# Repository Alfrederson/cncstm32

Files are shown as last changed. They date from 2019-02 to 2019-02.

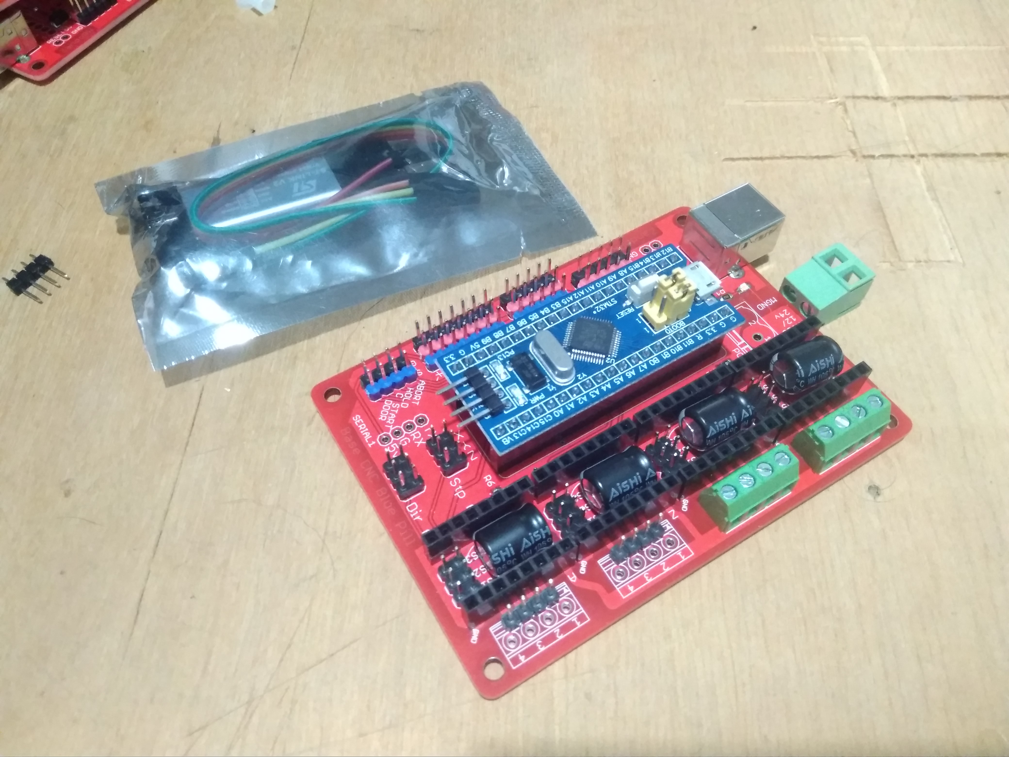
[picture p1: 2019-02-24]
physical board.jpg

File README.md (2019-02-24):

# cncstm32
CNC Base for Blue Pill

To be used with this port of GRBL for STM32F103F8T6: https://github.com/usbcnc/grbl or with Yaroslav's bugfixed and improved version:
https://github.com/yaroslavVl/6-AXIS-USBCNC-GRBL .

This board works with either 3d printer drivers or with external drivers using MKS-CD adapter.
An adapter could be made so that drivers that use a common 5V instead of a common GND for step/dir/enable (e.g: the aliexpress TB6600 drivers that come in a black aluminum enclosure) could be used as well.

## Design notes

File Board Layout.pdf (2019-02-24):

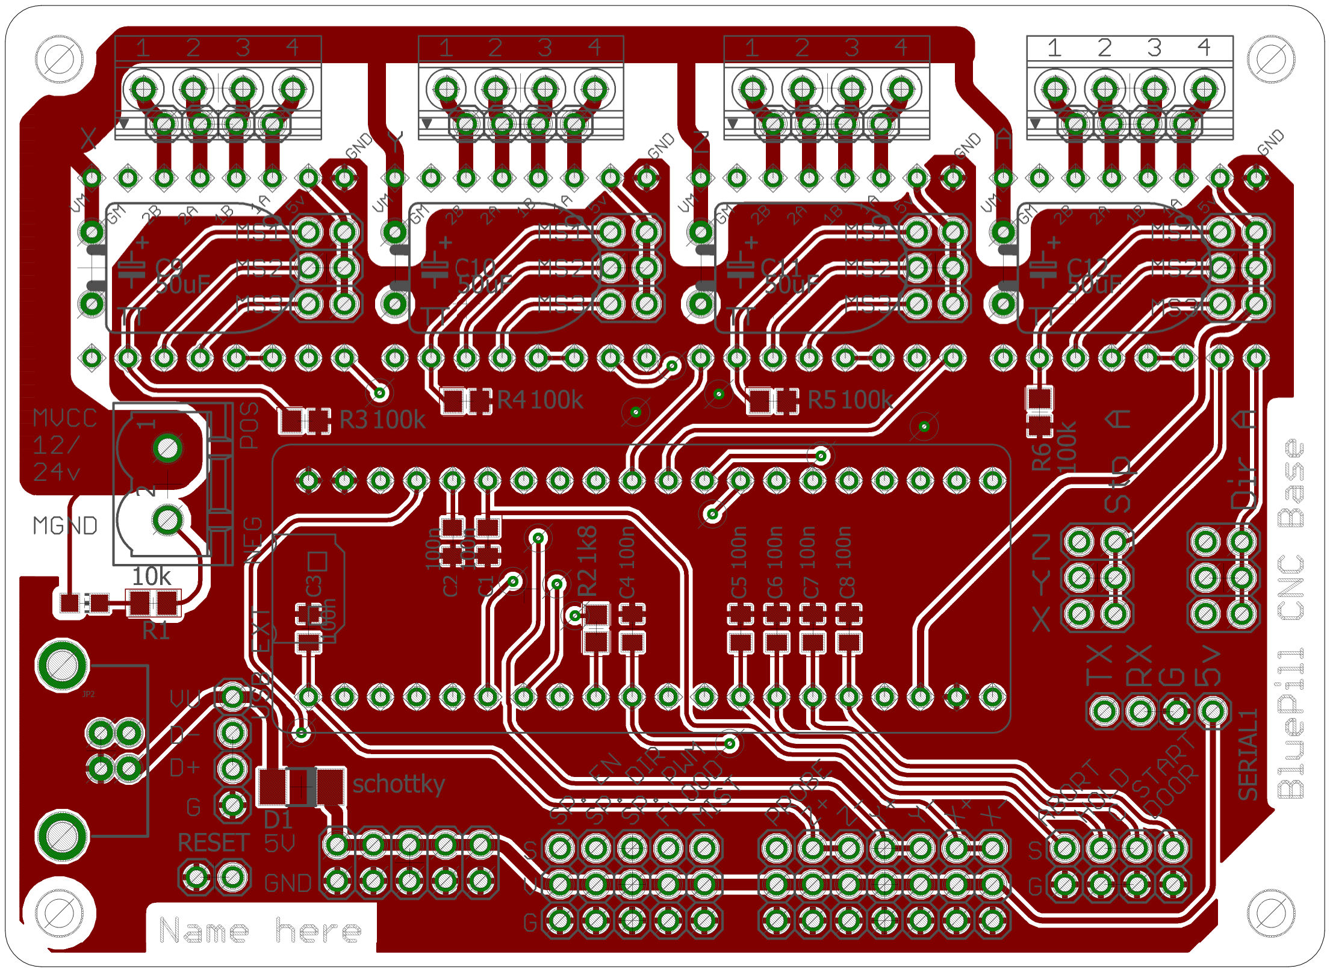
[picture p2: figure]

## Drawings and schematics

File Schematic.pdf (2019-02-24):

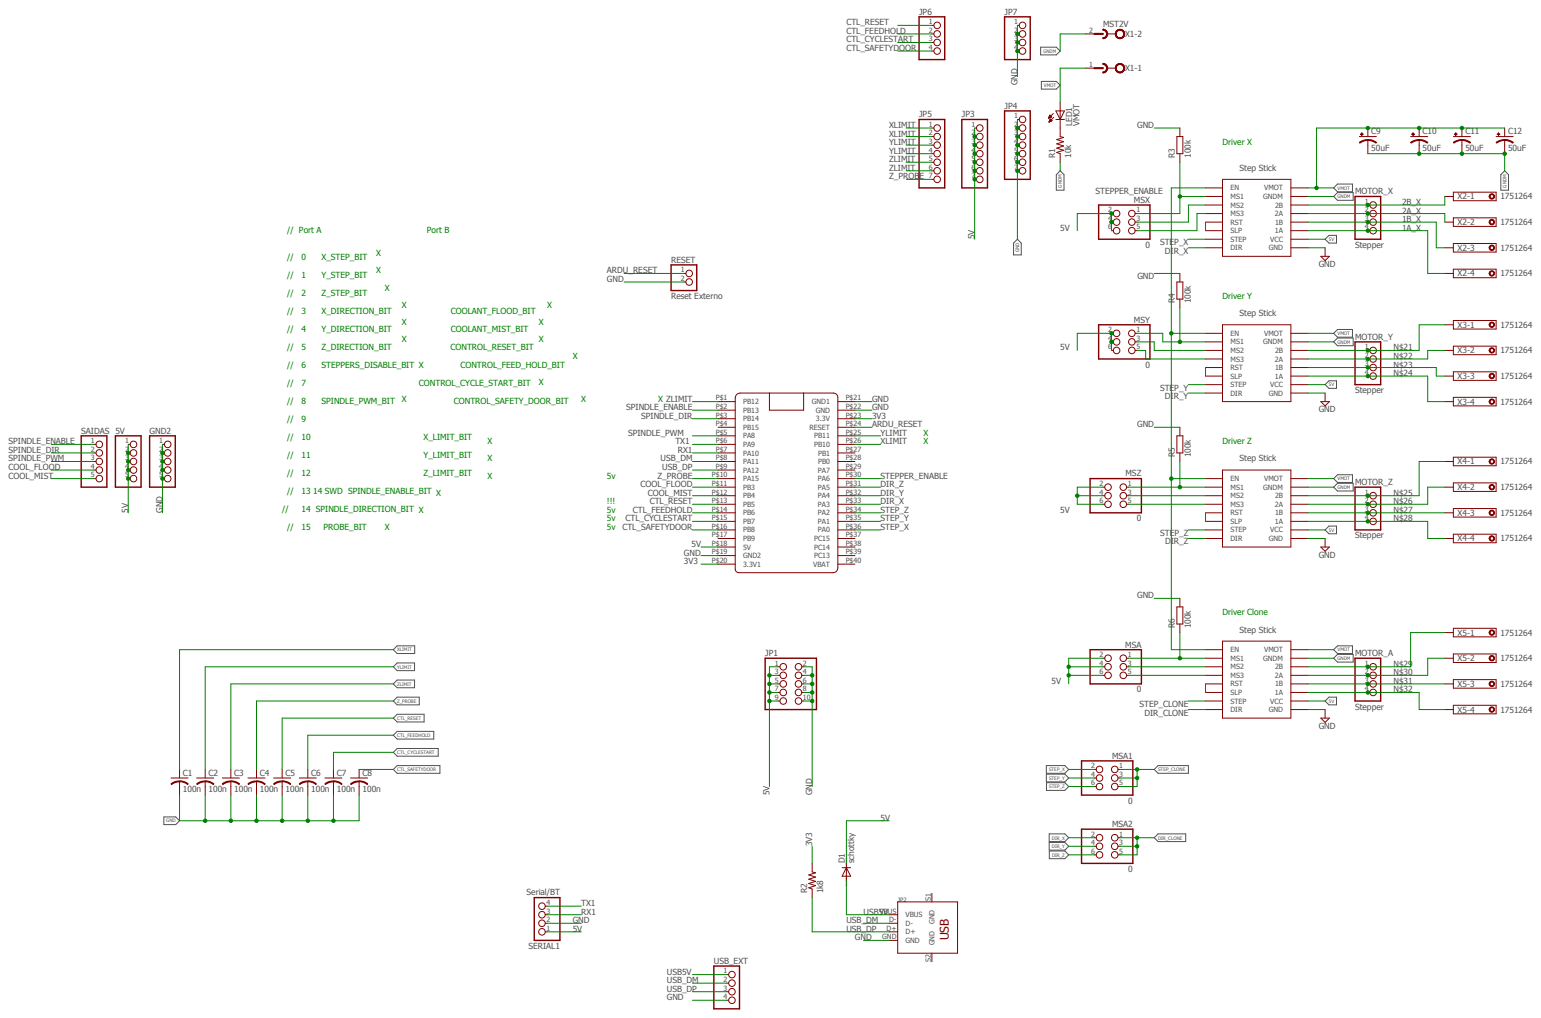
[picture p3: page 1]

3 | 1B_X
4 | 1A_X

2 | N$22
4 | N$24

2 | N$26

2 | N$30

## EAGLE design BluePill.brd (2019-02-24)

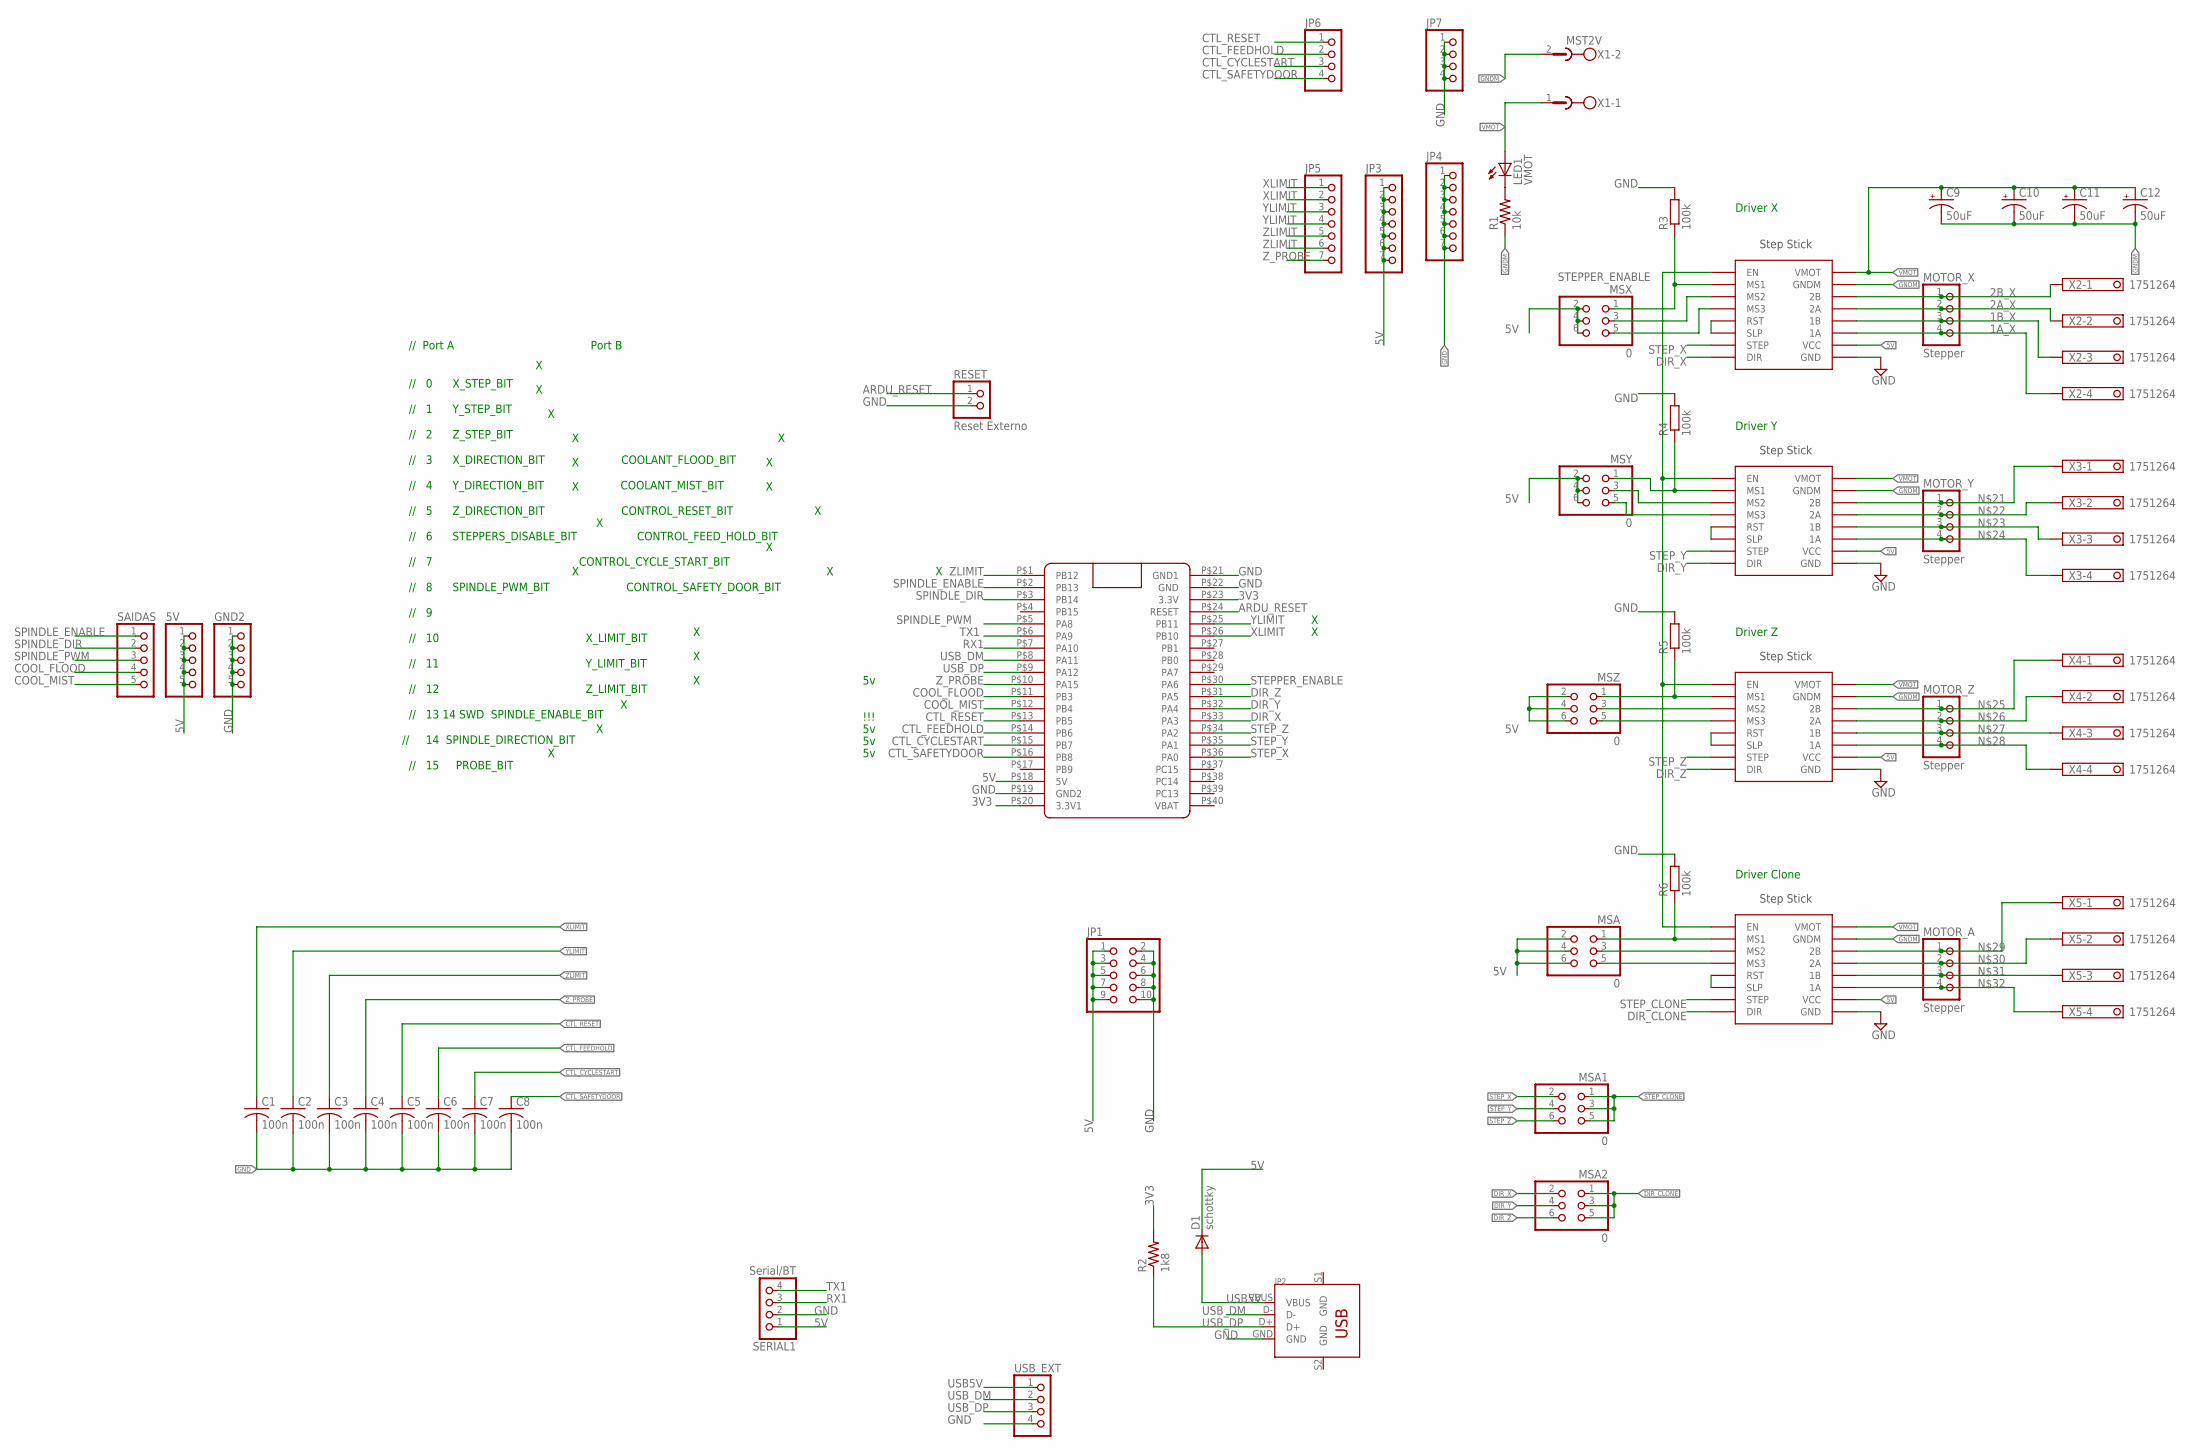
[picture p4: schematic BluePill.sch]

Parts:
5V: PINHD-1X5; 1X05
C1, C2, C3, C4, C5, C6, C7, C8: 100n; C0805K
C9, C10, C11, C12: 50uF; TT5D9L
D1: schottky; DO-214AC
DRIVER_CLONE: STEP-STICK
DRIVER_X: STEP-STICK
DRIVER_Y: STEP-STICK
DRIVER_Z: STEP-STICK
GND2: PINHD-1X5; 1X05
JP1: PINHD-2X5; 2X05
JP2: DIP-USB-B-TYPE-FMAL(4+2P-2.0-90D); USB4+2-2.5-90D-15.8X12MM
JP3, JP4, JP5: PINHD-1X7; 1X07
JP6, JP7: PINHD-1X4; 1X04
LED1: VMOT; CHIP-LED0805
MOTOR_A: Stepper; 1X04
MOTOR_X: Stepper; 1X04
MOTOR_Y: Stepper; 1X04
MOTOR_Z: Stepper; 1X04
MSA, MSA1, MSA2: 0; 2X03
MSX: 0; 2X03
MSY: 0; 2X03
MSZ: 0; 2X03
R1: 10k; M0805
R2: 1k8; R0805
R3, R4, R5, R6: 100k; R0805
RESET: Reset Externo; 1X02
SAIDAS: PINHD-1X5; 1X05
SERIAL1: Serial/BT; 1X04
U$1: BLUE_PILL
USB_EXT: PINHD-1X4; 1X04
X1: MST2V; MSTBV2
X2, X3, X4, X5: 1751264

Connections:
1A_X: DRIVER_X.1A, MOTOR_X.4, X2.4
1B_X: DRIVER_X.1B, MOTOR_X.3, X2.3
2A_X: DRIVER_X.2A, MOTOR_X.2, X2.2
2B_X: DRIVER_X.2B, MOTOR_X.1, X2.1
3V3: R2.2, U$1.P$20 (3.3V1), U$1.P$23 (3.3V)
5V: 5V.1, 5V.2, 5V.3, 5V.4, 5V.5, D1.C, DRIVER_CLONE.VCC, DRIVER_X.VCC, DRIVER_Y.VCC, DRIVER_Z.VCC, JP1.1, JP1.3, JP1.5, JP1.7, JP1.9, JP3.1, JP3.2, JP3.3, JP3.4, JP3.5, JP3.6, JP3.7, MSA.2, MSA.4, MSA.6, MSX.2, MSX.4, MSX.6, MSY.2, MSY.4, MSY.6, MSZ.2, MSZ.4, MSZ.6, SERIAL1.1, U$1.P$18 (5V)
AMS1: DRIVER_CLONE.MS1, MSA.1, R6.1
AMS2: DRIVER_CLONE.MS2, MSA.3
AMS3: DRIVER_CLONE.MS3, MSA.5
ARDU_RESET: RESET.1, U$1.P$24 (RESET)
COOL_FLOOD: SAIDAS.4, U$1.P$11 (PB3)
COOL_MIST: SAIDAS.5, U$1.P$12 (PB4)
CTL_CYCLESTART: C7.1, JP6.3, U$1.P$15 (PB7)
CTL_FEEDHOLD: C6.1, JP6.2, U$1.P$14 (PB6)
CTL_RESET: C5.1, JP6.1, U$1.P$13 (PB5)
CTL_SAFETYDOOR: C8.1, JP6.4, U$1.P$16 (PB8)
DIR_CLONE: DRIVER_CLONE.DIR, MSA2.1, MSA2.3, MSA2.5
DIR_X: DRIVER_X.DIR, MSA2.2, U$1.P$33 (PA3)
DIR_Y: DRIVER_Y.DIR, MSA2.4, U$1.P$32 (PA4)
DIR_Z: DRIVER_Z.DIR, MSA2.6, U$1.P$31 (PA5)
GND: C1.2, C2.2, C3.2, C4.2, C5.2, C6.2, C7.2, C8.2, DRIVER_CLONE.GND, DRIVER_X.GND, DRIVER_Y.GND, DRIVER_Z.GND, GND2.1, GND2.2, GND2.3, GND2.4, GND2.5, JP1.2, JP1.4, JP1.6, JP1.8, JP1.10, JP2.GND, JP4.1, JP4.2, JP4.3, JP4.4, JP4.5, JP4.6, JP4.7, JP7.1, JP7.2, JP7.3, JP7.4, R3.2, R4.2, R5.2, R6.2, RESET.2, SERIAL1.2, U$1.P$19 (GND2), U$1.P$21 (GND1), U$1.P$22 (GND), USB_EXT.4
GNDM: C9.-, C10.-, C11.-, C12.-, DRIVER_CLONE.GNDM, DRIVER_X.GNDM, DRIVER_Y.GNDM, DRIVER_Z.GNDM, R1.1, X1.2
MS1: DRIVER_X.MS1, MSX.1, R3.1
MS2: DRIVER_X.MS2, MSX.3
MS3: DRIVER_X.MS3, MSX.5
unnamed: DRIVER_X.RST, DRIVER_X.SLP
unnamed: DRIVER_Y.RST, DRIVER_Y.SLP
unnamed: DRIVER_Z.RST, DRIVER_Z.SLP
unnamed: DRIVER_CLONE.RST, DRIVER_CLONE.SLP
unnamed: DRIVER_Y.2B, MOTOR_Y.1, X3.1
unnamed: DRIVER_Y.2A, MOTOR_Y.2, X3.2
unnamed: DRIVER_Y.1B, MOTOR_Y.3, X3.3
unnamed: DRIVER_Y.1A, MOTOR_Y.4, X3.4
unnamed: DRIVER_Z.2B, MOTOR_Z.1, X4.1
unnamed: DRIVER_Z.2A, MOTOR_Z.2, X4.2
unnamed: DRIVER_Z.1B, MOTOR_Z.3, X4.3
unnamed: DRIVER_Z.1A, MOTOR_Z.4, X4.4
unnamed: DRIVER_CLONE.2B, MOTOR_A.1, X5.1
unnamed: DRIVER_CLONE.2A, MOTOR_A.2, X5.2
unnamed: DRIVER_CLONE.1B, MOTOR_A.3, X5.3
unnamed: DRIVER_CLONE.1A, MOTOR_A.4, X5.4
unnamed: LED1.C, R1.2
RX1: SERIAL1.3, U$1.P$7 (PA10)
SPINDLE_DIR: SAIDAS.2, U$1.P$3 (PB14)
SPINDLE_ENABLE: SAIDAS.1, U$1.P$2 (PB13)
SPINDLE_PWM: SAIDAS.3, U$1.P$5 (PA8)
STEPPER_ENABLE: DRIVER_CLONE.EN, DRIVER_X.EN, DRIVER_Y.EN, DRIVER_Z.EN, U$1.P$30 (PA6)
STEP_CLONE: DRIVER_CLONE.SPT (STEP), MSA1.1, MSA1.3, MSA1.5
STEP_X: DRIVER_X.SPT (STEP), MSA1.2, U$1.P$36 (PA0)
STEP_Y: DRIVER_Y.SPT (STEP), MSA1.4, U$1.P$35 (PA1)
STEP_Z: DRIVER_Z.SPT (STEP), MSA1.6, U$1.P$34 (PA2)
TX1: SERIAL1.4, U$1.P$6 (PA9)
USB5V: D1.A, JP2.VBUS, USB_EXT.1
USB_DM: JP2.D-, U$1.P$8 (PA11), USB_EXT.2
USB_DP: JP2.D+, R2.1, U$1.P$9 (PA12), USB_EXT.3
VMOT: C9.+, C10.+, C11.+, C12.+, DRIVER_CLONE.VMOT, DRIVER_X.VMOT, DRIVER_Y.VMOT, DRIVER_Z.VMOT, LED1.A, X1.1
XLIMIT: C1.1, JP5.1, JP5.2, U$1.P$26 (PB10)
YLIMIT: C2.1, JP5.3, JP5.4, U$1.P$25 (PB11)
YMS1: DRIVER_Y.MS1, MSY.1, R4.1
YMS2: DRIVER_Y.MS2, MSY.3
YMS3: DRIVER_Y.MS3, MSY.5
ZLIMIT: C3.1, JP5.5, JP5.6, U$1.P$1 (PB12)
ZMS1: DRIVER_Z.MS1, MSZ.1, R5.1
ZMS2: DRIVER_Z.MS2, MSZ.3
ZMS3: DRIVER_Z.MS3, MSZ.5
Z_PROBE: C4.1, JP5.7, U$1.P$10 (PA15)

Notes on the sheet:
Driver X
Driver Y
Driver Z
Driver Clone
// Port A Port B // 0 X_STEP_BIT // 1 Y_STEP_BIT // 2 Z_STEP_BIT // 3 X_DIRECTION_BIT COOLANT_FLOOD_BIT // 4 Y_DIRECTION_BIT COOLANT_MIST_BIT // 5 Z_DIRECTION_BIT CONTROL_RESET_BIT // 6 STEPPERS_DISABLE_BIT CONTROL_FEED_HOLD_BIT // 7 CONTROL_CYCLE_START_BIT // 8 SPINDLE_PWM_BIT CONTROL_SAFETY_DOOR_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
!!!

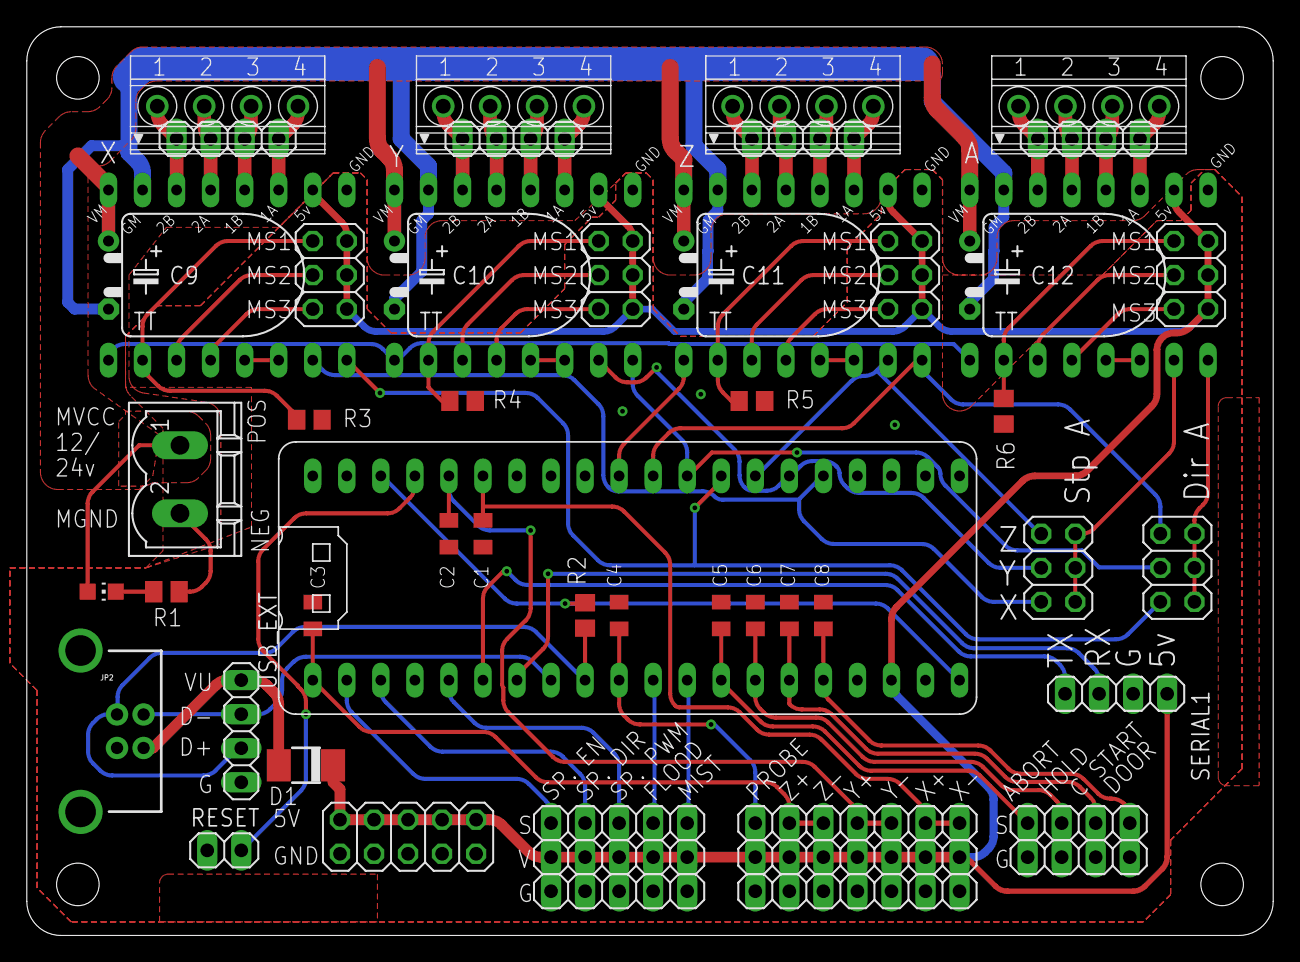
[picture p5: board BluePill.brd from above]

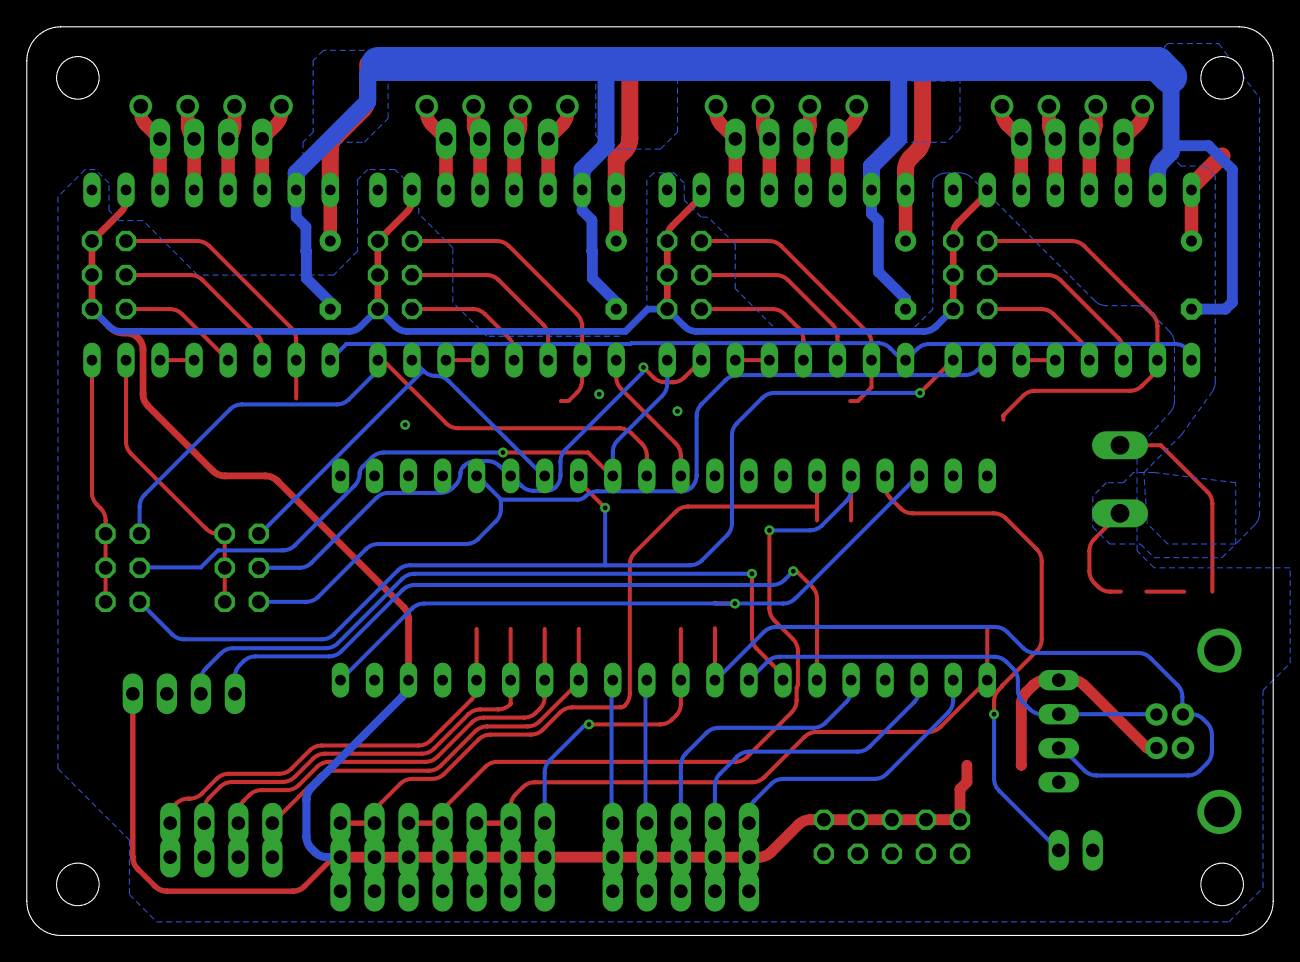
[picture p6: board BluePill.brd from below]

Board: 2 copper layers, 93.0 x 67.8 mm, 53 parts (4 on the bottom side), 66 nets.

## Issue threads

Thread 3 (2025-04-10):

pcb problem ?

sasan18s, 2025-04-10:
hi . thank for this good design and share it with others . your a good man ,
i have some problem in pcb file :

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

and some question ....
-can we use some EEPROM  ic to make this circuit faster and responsive for longer time like some AT24C128  ?
-in the micro controller logic voltage we have 3v3 but for ( SPINDLE_ENABLE - SPINDLE_DIR -SPINDLE_PWM-COOL_FLOOD-COOL_MIST - and LIMIT switches) you use 5v trigger  .  that not make micro problem ?
-with this program usb work correctly? and directly ?and we dont need the st-link (after first program ) and and serial thing like ch340g ?
just direct connect and boom usb work ?
-the last thing can i use it for laser control and use it in Lightburn program ? should any thing change for diode laser (10w - laser tree 24v )  control ?

thank you Friend ;)

sasan18s, 2025-04-10:
look at this . is the pcb know ok ?

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

Alfrederson, 2025-04-11:
Yes, when you do the rat nest and generate the gerbers/mask the polygons merge and it will work

If you burn the .hex into the stm32 it will use the built in USB interface, I think it identifies as a com port

The pins on the mcu are supposed to be 5v tolerant

I know at least one person who used this with a diode laser, but personally I haven't tried it yet

sasan18s, 2025-04-11:
thanks for your answer and helping . i want to test to it with the laser and light burn .
i think should use 74ACT245 with the pcb for switch 3v3 to 5v and some EL817 optocoupler for Limits switch & etc ... that make 5v Problem going to zero because i think the stm32 have 3v3 logical I/O and with the 5v It Going To Burn The Dip .

Closed 2025-04-11.

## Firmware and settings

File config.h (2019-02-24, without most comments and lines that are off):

#define config_h
#include "grbl.h" // For Arduino IDE compatibility.
#define ABC_AXIS_EXAMPLE
#ifdef WIN32
#define CPU_MAP_WIN32
#endif
#ifdef AVRTARGET
#define CPU_MAP_ATMEGA328P // Arduino Uno CPU
#endif
#define AA_AXIS // Disabled by default. Uncomment to enable.
#define BAUD_RATE 115200
#define CMD_RESET 0x18 // ctrl-x.
#define CMD_STATUS_REPORT '?'
#define CMD_CYCLE_START '~'
#define CMD_FEED_HOLD '!'
#define CMD_SAFETY_DOOR 0x84
#define CMD_JOG_CANCEL  0x85
#define CMD_DEBUG_REPORT 0x86 // Only when DEBUG enabled, sends debug report in '{}' braces.
#define CMD_FEED_OVR_RESET 0x90         // Restores feed override value to 100%.
#define CMD_FEED_OVR_COARSE_PLUS 0x91
#define CMD_FEED_OVR_COARSE_MINUS 0x92
#define CMD_FEED_OVR_FINE_PLUS  0x93
#define CMD_FEED_OVR_FINE_MINUS  0x94
#define CMD_RAPID_OVR_RESET 0x95        // Restores rapid override value to 100%.
#define CMD_RAPID_OVR_MEDIUM 0x96
#define CMD_RAPID_OVR_LOW 0x97
#define CMD_SPINDLE_OVR_RESET 0x99      // Restores spindle override value to 100%.
#define CMD_SPINDLE_OVR_COARSE_PLUS 0x9A
#define CMD_SPINDLE_OVR_COARSE_MINUS 0x9B
#define CMD_SPINDLE_OVR_FINE_PLUS 0x9C
#define CMD_SPINDLE_OVR_FINE_MINUS 0x9D
#define CMD_SPINDLE_OVR_STOP 0x9E
#define CMD_COOLANT_FLOOD_OVR_TOGGLE 0xA0
#define CMD_COOLANT_MIST_OVR_TOGGLE 0xA1
#define HOMING_INIT_LOCK // Comment to disable
#if defined AA_AXIS
#define HOMING_CYCLE_0 (1<<Z_AXIS)                // REQUIRED: First move Z to clear workspace.
#define HOMING_CYCLE_1 ((1<<X_AXIS)|(1<<Y_AXIS))  // OPTIONAL: Then move X,Y at the same time.
#define HOMING_CYCLE_2 (1<<A_AXIS)                // OPTIONAL: Then move A
#elif defined AB_AXIS
#define HOMING_CYCLE_0 (1<<Z_AXIS)                // REQUIRED: First move Z to clear workspace.
#define HOMING_CYCLE_1 ((1<<X_AXIS)|(1<<Y_AXIS))  // OPTIONAL: Then move X,Y at the same time.
#define HOMING_CYCLE_2 ((1<<A_AXIS)|(1<<B_AXIS))  // OPTIONAL: Then move A,B at the same time.
#elif defined ABC_AXIS
#define HOMING_CYCLE_0 (1<<Z_AXIS)                // REQUIRED: First move Z to clear workspace.
#define HOMING_CYCLE_1 ((1<<X_AXIS)|(1<<Y_AXIS))  // OPTIONAL: Then move X,Y at the same time.
#define HOMING_CYCLE_2 ((1<<A_AXIS)|(1<<B_AXIS)|(1<<C_AXIS)) // OPTIONAL: Then move A,B,C at the same time.
#else
#define HOMING_CYCLE_0 (1<<Z_AXIS)                // REQUIRED: First move Z to clear workspace.
#define HOMING_CYCLE_1 ((1<<X_AXIS)|(1<<Y_AXIS))  // OPTIONAL: Then move X,Y at the same time.
#endif
#define N_HOMING_LOCATE_CYCLE 1 // Integer (1-128)
#define N_STARTUP_LINE 2 // Integer (1-2)
#define N_DECIMAL_COORDVALUE_INCH 4 // Coordinate or position value in inches
#define N_DECIMAL_COORDVALUE_MM   3 // Coordinate or position value in mm
#define N_DECIMAL_RATEVALUE_INCH  1 // Rate or velocity value in in/min
#define N_DECIMAL_RATEVALUE_MM    0 // Rate or velocity value in mm/min
#define N_DECIMAL_SETTINGVALUE    3 // Decimals for floating point setting values
#define N_DECIMAL_RPMVALUE        0 // RPM value in rotations per min.
#define MESSAGE_PROBE_COORDINATES // Enabled by default. Comment to disable.
 #define ENABLE_M7 // Disabled by default. Uncomment to enable.
#define SAFETY_DOOR_SPINDLE_DELAY 4.0 // Float (seconds)
#define SAFETY_DOOR_COOLANT_DELAY 1.0 // Float (seconds)
#define CHECK_LIMITS_AT_INIT
#define DEFAULT_FEED_OVERRIDE           100 // 100%. Don't change this value.
#define MAX_FEED_RATE_OVERRIDE          200 // Percent of programmed feed rate (100-255). Usually 120% or 200%
#define MIN_FEED_RATE_OVERRIDE           10 // Percent of programmed feed rate (1-100). Usually 50% or 1%
#define FEED_OVERRIDE_COARSE_INCREMENT   10 // (1-99). Usually 10%.
#define FEED_OVERRIDE_FINE_INCREMENT      1 // (1-99). Usually 1%.
#define DEFAULT_RAPID_OVERRIDE  100 // 100%. Don't change this value.
#define RAPID_OVERRIDE_MEDIUM    50 // Percent of rapid (1-99). Usually 50%.
#define RAPID_OVERRIDE_LOW       25 // Percent of rapid (1-99). Usually 25%.
#define DEFAULT_SPINDLE_SPEED_OVERRIDE    100 // 100%. Don't change this value.
#define MAX_SPINDLE_SPEED_OVERRIDE        200 // Percent of programmed spindle speed (100-255). Usually 200%.
#define MIN_SPINDLE_SPEED_OVERRIDE         10 // Percent of programmed spindle speed (1-100). Usually 10%.
#define SPINDLE_OVERRIDE_COARSE_INCREMENT  10 // (1-99). Usually 10%.
#define SPINDLE_OVERRIDE_FINE_INCREMENT     1 // (1-99). Usually 1%.
#define RESTORE_OVERRIDES_AFTER_PROGRAM_END // Default enabled. Comment to disable.
#define REPORT_FIELD_BUFFER_STATE // Default enabled. Comment to disable.
#define REPORT_FIELD_PIN_STATE // Default enabled. Comment to disable.
#define REPORT_FIELD_CURRENT_FEED_SPEED // Default enabled. Comment to disable.
#define REPORT_FIELD_WORK_COORD_OFFSET // Default enabled. Comment to disable.
#define REPORT_FIELD_OVERRIDES // Default enabled. Comment to disable.
#define REPORT_FIELD_LINE_NUMBERS // Default enabled. Comment to disable.
#define REPORT_OVR_REFRESH_BUSY_COUNT 20  // (1-255)
#define REPORT_OVR_REFRESH_IDLE_COUNT 10  // (1-255) Must be less than or equal to the busy count
#define REPORT_WCO_REFRESH_BUSY_COUNT 30  // (2-255)
#define REPORT_WCO_REFRESH_IDLE_COUNT 10  // (2-255) Must be less than or equal to the busy count
#define ACCELERATION_TICKS_PER_SECOND 100
#define ADAPTIVE_MULTI_AXIS_STEP_SMOOTHING  // Default enabled. Comment to disable.
#define TOOL_LENGTH_OFFSET_AXIS Z_AXIS // Default z-axis. Valid values are X_AXIS, Y_AXIS, or Z_AXIS.
#define VARIABLE_SPINDLE // Default enabled. Comment to disable.
#define USE_SPINDLE_ENABLE_PIN // Default enabled. Comment to disable.
#define MINIMUM_JUNCTION_SPEED 0.0f // (mm/min)
#define MINIMUM_FEED_RATE 1.0 // (mm/min)
#define N_ARC_CORRECTION 12 // Integer (1-255)
#define ARC_ANGULAR_TRAVEL_EPSILON 5E-7 // Float (radians)
#define DWELL_TIME_STEP 50 // Integer (1-255) (milliseconds)
#define ENABLE_RESTORE_EEPROM_WIPE_ALL         // '$RST=*' Default enabled. Comment to disable.
#define ENABLE_RESTORE_EEPROM_DEFAULT_SETTINGS // '$RST=$' Default enabled. Comment to disable.
#define ENABLE_RESTORE_EEPROM_CLEAR_PARAMETERS // '$RST=#' Default enabled. Comment to disable.
#define ENABLE_BUILD_INFO_WRITE_COMMAND // '$I=' Default enabled. Comment to disable.
#define FORCE_BUFFER_SYNC_DURING_EEPROM_WRITE // Default enabled. Comment to disable.
#define FORCE_BUFFER_SYNC_DURING_WCO_CHANGE // Default enabled. Comment to disable.
#define PARKING_AXIS Z_AXIS // Define which axis that performs the parking motion
#define PARKING_TARGET -5.0f // Parking axis target. In mm, as machine coordinate [-max_travel,0].
#define PARKING_RATE 500.0f // Parking fast rate after pull-out in mm/min.
#define PARKING_PULLOUT_RATE 100.0f // Pull-out/plunge slow feed rate in mm/min.
#define PARKING_PULLOUT_INCREMENT 5.0f // Spindle pull-out and plunge distance in mm. Incremental distance.
#define DISABLE_LASER_DURING_HOLD // Default enabled. Comment to disable.
#define N_PIECES 4  // Integer (1-4). Number of piecewise lines used in script solution.
#define RPM_MAX  11686.4  // Max RPM of model. $30 > RPM_MAX will be limited to RPM_MAX.
#define RPM_MIN  202.5    // Min RPM of model. $31 < RPM_MIN will be limited to RPM_MIN.
#define RPM_POINT12  6145.4  // Used N_PIECES >=2. Junction point between lines 1 and 2.
#define RPM_POINT23  9627.8  // Used N_PIECES >=3. Junction point between lines 2 and 3.
#define RPM_POINT34  10813.9 // Used N_PIECES = 4. Junction point between lines 3 and 4.
#define RPM_LINE_A1  3.197101e-03  // Used N_PIECES >=1. A and B constants of line 1.
#define RPM_LINE_B1  -3.526076e-1
#define RPM_LINE_A2  1.722950e-2   // Used N_PIECES >=2. A and B constants of line 2.
#define RPM_LINE_B2  8.588176e+01
#define RPM_LINE_A3  5.901518e-02  // Used N_PIECES >=3. A and B constants of line 3.
#define RPM_LINE_B3  4.881851e+02
#define RPM_LINE_A4  1.203413e-01  // Used N_PIECES = 4. A and B constants of line 4.
#define RPM_LINE_B4  1.151360e+03

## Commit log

2018-11-07 Add files via upload
    Primeira revisão
    [BluePill.brd, BluePill.sch]
2019-02-24 Create gerber

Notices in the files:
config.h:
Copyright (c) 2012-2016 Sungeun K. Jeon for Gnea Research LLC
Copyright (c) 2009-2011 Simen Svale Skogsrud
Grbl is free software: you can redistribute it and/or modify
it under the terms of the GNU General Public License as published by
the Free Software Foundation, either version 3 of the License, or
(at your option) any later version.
